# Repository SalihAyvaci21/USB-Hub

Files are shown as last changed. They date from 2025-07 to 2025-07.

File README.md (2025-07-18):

# USB Hub + PD Controller Projesi

Bu proje, USB-C PD (Power Delivery) desteği ile çalışan, 5V-24V arası giriş voltajını kabul eden ve gücü dört farklı çıkışa dağıtan bir **USB Hub** tasarımıdır. Güç ve sinyal yönetimi için çeşitli koruma ve anahtarlama IC’leri entegre edilmiştir.

## 📦 Özellikler

- **Giriş Voltajı (USB-C):** 5V - 24V (PD destekli)
- **Çıkışlar:**
  - 1x **USB-A 3.0**
  - 1x **USB-C 3.0**
  - 1x **FTDI (UART-USB dönüştürücü)**
  - 1x **ST-Link (Programlayıcı / Debugger)**
- **PD Controller:** CH224K (Switch ile kontrol)
- **USB Hub IC:** TUSB8044ARGCR
- **Sinyal Yönlendirme:**
  - 2x HD3SS3202IRSVR (SS MUX, C-to-A ve A-to-C için)
- **Koruma Devreleri:**
  - TPD6S300A (ESD ve güç koruması)
- **Güç Regülasyonu:**
  - 1.1V: TLV71211 (SOT23-5)
  - 3.3V: NCP1117-3.3 (SOT-223)
  - 5V: KA78M05 (TO-252)
- **Programlayıcılar:**
  - ST-Link için STM32F103CBTx
  - FTDI için FT232RL-REEL

## 🛠 Bileşenler

| Bileşen | Açıklama |
|---|---|
| **CH224K** | USB-C PD Controller |
| **TUSB8044ARGCR** | USB 3.0 Hub Controller |
| **HD3SS3202IRSVR** | USB SS MUX (C/A anahtarlama) |
| **TPD6S300A** | USB-C koruma (ESD, VBUS) |
| **TLV71211** | 1.1V LDO Regülatör |
| **NCP1117-3.3** | 3.3V LDO Regülatör |
| **KA78M05** | 5V Regülatör |
| **STM32F103CBTx** | ST-Link Programlayıcı MCU |
| **FT232RL-REEL** | FTDI USB-UART dönüştürücü |

## 📐 Tasarım Özellikleri

- **PD Desteği:** 5V ila 24V arası giriş voltajını otomatik algılar entegre doğru çıkışı verir.
- **Güç Dağıtımı:** TUSB8044ARGCR ile USB 3.0 sinyalleri dört porta bölünür.
- **Sinyal Yönlendirme:** HD3SS3202 ile USB-C ve USB-A arasında yüksek hızlı sinyal yönlendirme.
- **Güvenlik:** TPD6S300A ile USB-C girişinde aşırı gerilim ve ESD koruması.
- **Programlama ve Debug:** Dahili ST-Link (STM32F103CBTx) ve FTDI (FT232RL) arayüzleri.

## 🔌 Kullanım

1. **Giriş Bağlantısı:**
   - USB-C PD girişine adaptör bağlayın (5V-24V arası desteklenir).
2. **Çıkışlar:**
   - USB-A 3.0 portuna cihaz bağlanabilir.
   - USB-C 3.0 portu yüksek hızlı veri aktarımı için kullanılabilir.
   - FTDI portu UART bağlantısı için kullanılabilir.
   - ST-Link portu STM32 debug/programlama için hazırdır.

## ⚡ Koruma ve Güvenlik

- **ESD Koruma:** TPD6S300A
- **Aşırı Gerilim:** PD kontrolcü ile voltaj sınırlaması
- **Sinyal Integrity:** SS MUX ile minimum sinyal kaybı

## 📁 Dosyalar

- `Usb 3. v11.kicad_pro` – KiCAD proje dosyası
- `Usb 3. v11.kicad_sch` – Devre şeması
- `gerber` – Üretim için Gerber dosyaları 
- `BomList.xlsx` – Parça listesi

## ⚠️ Dikkat

> Bu tasarım yüksek hızlı USB sinyalleri ve PD voltajları içerir. Geliştirme ve test sırasında uygun yalıtım ve ESD önlemleri alınmalıdır.

## 📜 Lisans

Bu proje açık kaynaklıdır ve kişisel/akademik kullanım için serbesttir.

---

# USB Hub + PD Controller Project

This project is a **USB Hub** design that operates with USB-C PD (Power Delivery) support, accepting an input voltage range of 5V-24V and distributing power across four different outputs. Various protection and switching ICs are integrated for power and signal management.

## 📦 Features

- **Input Voltage (USB-C):** 5V - 24V (PD supported)
- **Outputs:**
  - 1x **USB-A 3.0**
  - 1x **USB-C 3.0**
  - 1x **FTDI (UART-USB converter)**
  - 1x **ST-Link (Programmer / Debugger)**
- **PD Controller:** CH224K (controlled via switch)
- **USB Hub IC:** TUSB8044ARGCR
- **Signal Routing:**
  - 2x HD3SS3202IRSVR (SS MUX for C-to-A and A-to-C)
- **Protection Circuits:**
  - TPD6S300A (ESD and power protection)
- **Power Regulation:**
  - 1.1V: TLV71211 (SOT23-5)
  - 3.3V: NCP1117-3.3 (SOT-223)
  - 5V: KA78M05 (TO-252)
- **Programmers:**
  - STM32F103CBTx for ST-Link
  - FT232RL-REEL for FTDI

## 🛠 Components

| Component | Description |
|---|---|
| **CH224K** | USB-C PD Controller |
| **TUSB8044ARGCR** | USB 3.0 Hub Controller |
| **HD3SS3202IRSVR** | USB SS MUX (C/A switching) |
| **TPD6S300A** | USB-C protection (ESD, VBUS) |
| **TLV71211** | 1.1V LDO Regulator |
| **NCP1117-3.3** | 3.3V LDO Regulator |
| **KA78M05** | 5V Regulator |
| **STM32F103CBTx** | ST-Link Programmer MCU |
| **FT232RL-REEL** | FTDI USB-UART Converter |

## 📐 Design Features

- **PD Support:** Automatically detects input voltage between 5V and 24V and provides appropriate regulated output.
- **Power Distribution:** USB 3.0 signals are distributed to four ports using TUSB8044ARGCR.
- **Signal Routing:** High-speed signal switching between USB-C and USB-A via HD3SS3202.
- **Protection:** Overvoltage and ESD protection on USB-C input using TPD6S300A.
- **Programming and Debugging:** Integrated ST-Link (STM32F103CBTx) and FTDI (FT232RL) interfaces.

## 🔌 Usage

1. **Input Connection:**
   - Connect an adapter to the USB-C PD input (supports 5V-24V).
2. **Outputs:**
   - USB-A 3.0 port can connect to devices.
   - USB-C 3.0 port supports high-speed data transfer.
   - FTDI port can be used for UART connections.
   - ST-Link port is ready for STM32 debugging/programming.

## ⚡ Protection and Safety

- **ESD Protection:** TPD6S300A
- **Overvoltage:** Voltage limitation via PD controller
- **Signal Integrity:** Minimal signal loss using SS MUX

## 📁 Files

- `Usb 3. v11.kicad_pro` – KiCAD project file
- `Usb 3. v11.kicad_sch` – Schematic file
- `gerber` – Gerber files for production
- `BomList.xlsx` – Bill of Materials

## ⚠️ Warning

> This design involves high-speed USB signals and PD voltages. Proper insulation and ESD precautions must be taken during development and testing.

## 📜 License

This project is open-source and free for personal and academic use.

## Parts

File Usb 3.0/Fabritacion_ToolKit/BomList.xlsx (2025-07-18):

Reference | Value | Digi-Key_PN | MPN | Qty | Supplier | Footprint
C1,C29,C30,C31,C38,C39,C40,C41,C47,C48,C49,C50,C51 | 0.1uF | 399-C0805C104M5RACTUTR-ND | C0805C104M5RACTU | 13 | digikey | Capacitor_SMD:C_0805_2012Metric
C2,C3,C4,C9,C10,C11,C12,C13 | 1uF | 1276-1066-2-ND | CL21B105KAFNNNE | 7 | digikey | Capacitor_SMD:C_0805_2012Metric
C5,C6,C19,C20 | 20pF | 399-C0805C180J5HACTUTR-ND | C0805C180J5HACTU | 2 | digikey | Capacitor_SMD:C_0805_2012Metric
 |  | 399-C0805C180J5HACTUTR-ND | C0805C180J5HACTU | 2 | digikey | Capacitor_SMD:C_0805_2012Metric
C22,C24,C25,C26 | 100nF | 2679-C0805X5R100-104KNE-CT-ND | C0805X5R100-104KNE-CT | 4 | digikey | Capacitor_SMD:C_0805_2012Metric
C35 | 4.7uF | 1276-1244-2-ND | CL21A475KAQNNNE | 1 | digikey | Capacitor_SMD:C_0805_2012Metric
C37 | 0.1uf | 311-1344-2-ND | CC0603KRX7R9BB104 | 1 | digikey | Capacitor_SMD:C_0805_2012Metric
D1,D3,D7,D8 | LTST-C190GKT | 160-1183-1-ND | LTST-C190GKT | 4 | digikey | LED_SMD:LED_0603_1608Metric_Pad1.05x0.95mm_HandSolder
D2 | LTST-C191KRKT | 160-1447-1-ND | LTST-C191KRKT | 1 | digikey | LED_SMD:LED_0603_1608Metric_Pad1.05x0.95mm_HandSolder
D4 | D_Schottky /20V/5A | RB081LAM-20TRTR-ND | RB081LAM-20TR | 1 | digikey | Diode_SMD:D_SOD-128
J1,J3 | KUSBX-SMT-CS2-B30TR | 2092-KUSBX-SMT-CS2-B30TR-ND | KUSBX-SMT-CS2-B30TR | 2 | digikey | KUSBX-SMT3-CS-BTR_KYC
J2 | Conn_01x06 | 2553-2044-1X06G00SB-ND | 2044-1X06G00SB | 1 | digikey | Connector_PinSocket_2.54mm:PinSocket_1x06_P2.54mm_Vertical
J6 | Conn_02x05_Odd_Even | 2553-2044-2X05G00SB-ND | 2044-2X05G00SB | 1 | digikey | Connector_PinSocket_1.27mm:PinSocket_2x05_P1.27mm_Vertical
J7 | USB3_A | GSB316441CEUTR-ND | GSB316441CEU | 1 | digikey | Connector_USB:USB3_A_Molex_48393-001
J8,J10 | USB_A | 2987-CU01SAV0S00-ND | CU01SAV0S00
J9 | Screw_Terminal_01x02 | 5831-1715330000-ND | 1715330000 | 1 | digikey | TerminalBlock:TerminalBlock_MaiXu_MX126-5.0-02P_1x02_P5.00mm
Q1 | BC817-25-TP | BC817-25-TPMSCT-ND | BC817-25-TP | 1 | digikey | Package_TO_SOT_SMD:SOT-23-3
R1 | 100k | 311-100KCRTR-ND | RC0805FR-07100KL | 1 | digikey | Resistor_SMD:R_0805_2012Metric
R2 | 90.9k %1 | 311-90.9KCRTR-ND | RC0805FR-0790K9L | 1 | digikey | Resistor_SMD:R_0805_2012Metric
R3 | 10k %1 | 311-10.0KLRCT-ND | RC0805FR-0710KL | 1 | digikey | Resistor_SMD:R_0805_2012Metric
R4 | 1M | 311-1.0MARTR-ND | RC0805JR-071ML | 1 | digikey | Resistor_SMD:R_0805_2012Metric
R5,R6,R8,R10,R16,R17 | 1k | 311-1.00KCRTR-ND | RC0805FR-071KL | 6 | digikey | Resistor_SMD:R_0805_2012Metric
R7 | 3.5ohm | P3.57KLTR-ND | ERJ-2RKF3571X | 1 | digikey | Resistor_SMD:R_0805_2012Metric
R9 | 0.53k %1 | 2019-RN73R1JTTD5300F100TR-ND | RN73R1JTTD5300F100 | 1 | digikey | Resistor_SMD:R_0805_2012Metric
R11,R12,R13,R14,R18,R19,R36,R40,R20,R21,R24 | 10k | 311-10.0KCRTR-ND | RC0805FR-0710KL | 11 | digikey | Resistor_SMD:R_0805_2012Metric
R20, R21,R24 | 100R | 311-100CRTR-ND | RC0805FR-07100RL | 2 | digikey | Resistor_SMD:R_0805_2012Metric
R25 | 39K | 311-39.0KCRTR-ND | RC0805FR-0739KL | 1 | digikey | Resistor_SMD:R_0805_2012Metric
R26 | 1.5K | RHM1.5KTR-ND | ESR10EZPJ1R5 | 1 | digikey | Resistor_SMD:R_0805_2012Metric
SW1 | SW_DIP_x03 | CT2093MS-ND | 209-3MS | 1 | digikey | Button_Switch_THT:SW_DIP_SPSTx03_Slide_6.7x9.18mm_W7.62mm_P2.54mm_LowProfile
SW2,SW3 | SW_Omron_B3FS | CKN12222-2-ND | PTS526SMG15SMTR2 LFS | 2 | digikey | Button_Switch_SMD:SW_SPST_Omron_B3FS-100xP
TP1,TP2,TP3,TP4,TP5,TP6,TP7,TP8,TP9,TP10,TP11,TP12,TP13 | TestPoint |  |  | 13 | digikey | Connector_Pin:Pin_D1.4mm_L8.5mm_W2.8mm_FlatFork
U1 | CH224K | A0641 | PD/QC/AFC Hızlı Şarj Tetikleme Modülü | 1 | robotronik | Package_SO:SSOP-10-1EP_3.9x4.9mm_P1mm_EP2.1x3.3mm
U2 | TUSB8044ARGCR | 296-53620-2-ND | TUSB8044ARGCR | 1 | digikey | Package_DFN_QFN:VQFN-64-1EP_9x9mm_P0.5mm_EP5.4x5.4mm_ThermalVias
U3 | TPD6S300A | 296-51856-2-ND | TPD6S300ARUKR | 1 | digikey | Package_DFN_QFN:WQFN-20-1EP_3x3mm_P0.4mm_EP1.7x1.7mm_ThermalVias
U4 | NCP1117-3.3_SOT223 | 863-NCP1117LPST33T3G | NCP1117LPST33T3G (https://eu.mouser.com/ProductDetail/onsemi/NCP1117LPST33T3G?qs=kbSN2QblFfKG9A4Foh4YYg%3D%3D) | 1 | digikey | Package_TO_SOT_SMD:SOT-223-3
U5 | STM32F103CBTx | 497-17380-2-ND | STM32F103CBT6TR | 1 | digikey | Package_QFP:LQFP-48_7x7mm_P0.5mm
U6,U8 | HD3SS3202IRSVR | 296-HD3SS3202IRSVRTR-ND | HD3SS3202IRSVR | 2 | digikey | Package_DFN_QFN:UQFN-16-1EP_4x4mm_P0.65mm_EP2.6x2.6mm_ThermalVias
U7 | FT232RL-REEL | 768-1007-1-ND | FT232RL-REEL | 1 | digikey | Package_SO:SSOP-28_5.3x10.2mm_P0.65mm
U9 | KA78M05_TO252 | 511-L7805CDT-TR | L7805CDT-TR | 1 | digikey | Package_TO_SOT_SMD:TO-252-2
U10 | TLV71211_SOT23-5 | 296-30593-2-ND | TLV71211DBVR | 1 | digikey | Package_TO_SOT_SMD:SOT-23-5
XTAL1 | 16Mhz | 535-12830-2-ND | ABLS7M2-16.000MHZ-D2Y-T | 1 | digikey | Crystal:Crystal_SMD_EuroQuartz_EQ161-2Pin_3.2x1.5mm_HandSoldering
Y1 | 24Mhz | ABLS7M2-24.000MHZ-D2Y-T | ABLS7M2-24.000MHZ-D2Y-T | 1 | digikey | Crystal:Crystal_SMD_EuroQuartz_MQ2-2Pin_7.0x5.0mm_HandSoldering

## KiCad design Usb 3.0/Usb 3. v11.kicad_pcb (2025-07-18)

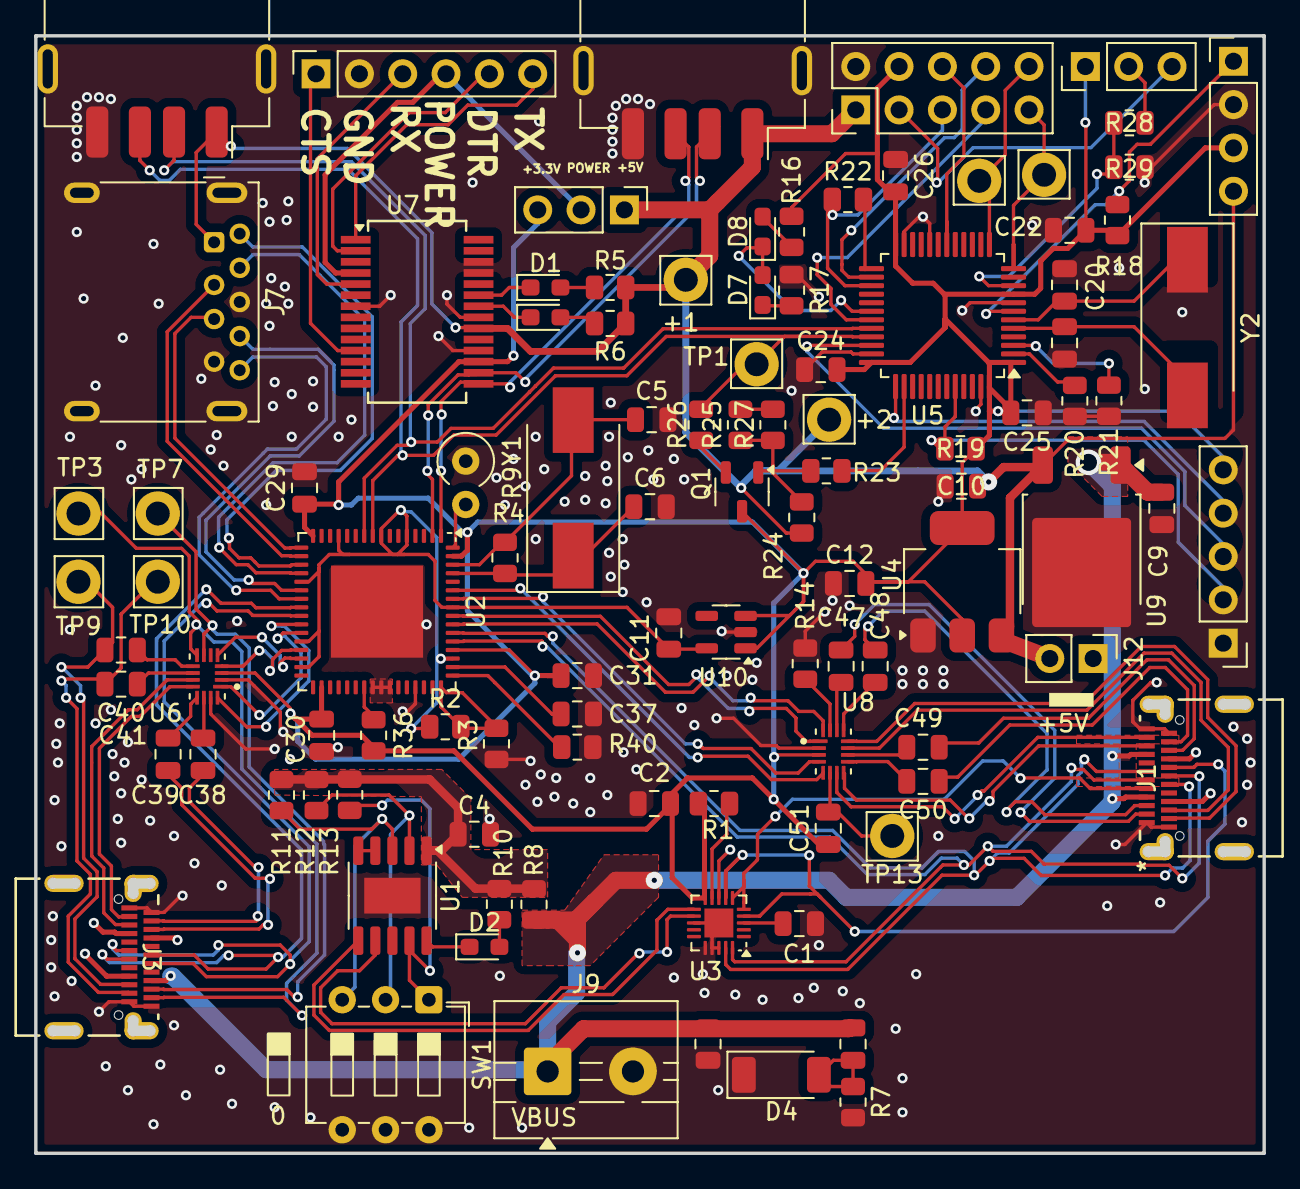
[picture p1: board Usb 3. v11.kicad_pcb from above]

Board: 2 copper layers, 72.0 x 65.5 mm, 103 parts (0 on the bottom side), 108 nets.

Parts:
+1, +2: TestPoint; Pin_D1.4mm_L8.5mm_W2.8mm_FlatFork
C1, C29, C30, C31, C38, C39, C40, C41, C47, C48, C49, C50, C51: 0.1uF; C_0805_2012Metric
C2, C3, C4, C9, C10, C11, C12: 1uF; C_0805_2012Metric
C5, C6, C19, C20: 20pF; C_0805_2012Metric
C22, C24, C25, C26: 100nF; C_0805_2012Metric
C35: 4.7uF; C_0805_2012Metric
C37: 0.1uf; C_0805_2012Metric
D1, D3, D7, D8: LTST-C190GKT; LED_0603_1608Metric_Pad1.05x0.95mm_HandSolder
D2: LTST-C191KRKT; LED_0603_1608Metric_Pad1.05x0.95mm_HandSolder
D4: D_Schottky /20V/5A; D_SOD-128
J1, J3: KUSBX-SMT-CS2-B30TR; KUSBX-SMT3-CS-BTR_KYC
J2: Conn_01x06; PinSocket_1x06_P2.54mm_Vertical
J4: Conn_01x03_Pin; PinHeader_1x03_P2.54mm_Vertical
J5: Conn_01x05_Pin; PinHeader_1x05_P2.54mm_Vertical
J6: Conn_02x05_Odd_Even; PinHeader_2x05_P2.54mm_Vertical
J7: USB3_A; USB3_A_Molex_48393-001
J8, J10: USB_A; USB_A_Receptacle_GCT_USB1046
J9: Screw_Terminal_01x02; TerminalBlock_MaiXu_MX126-5.0-02P_1x02_P5.00mm
J11: Conn_01x04_Pin; PinHeader_1x04_P2.54mm_Vertical
J12: Screw_Terminal_01x02; PinHeader_1x02_P2.54mm_Vertical
JP1: SolderJumper_3_Open; PinHeader_1x03_P2.54mm_Vertical
Q1: BC817-25-TP; SOT-23-3
R1: 100k; R_0805_2012Metric
R2: 90.9k %1; R_0805_2012Metric
R3: 10k %1; R_0805_2012Metric
R4: 1M; R_0805_2012Metric
R5, R6, R8, R10, R16, R17: 1k; R_0805_2012Metric
R7: 3.5ohm; R_0805_2012Metric
R9: 0.53k %1; R_Axial_DIN0309_L9.0mm_D3.2mm_P2.54mm_Vertical
R11, R12, R13, R14, R18, R19, R36, R40: 10k; R_0805_2012Metric
R20, R21, R24: 10K; R_0805_2012Metric
R22, R23: 100R; R_0805_2012Metric
R25: 39K; R_0805_2012Metric
R26: 1.5k; R_0805_2012Metric
R27: 33K; R_0805_2012Metric
R28, R29: 4.7k; R_0805_2012Metric
SW1: SW_DIP_x03; SW_DIP_SPSTx03_Slide_6.7x9.18mm_W7.62mm_P2.54mm_LowProfile
TP1, TP3, TP5, TP6, TP7, TP9, TP10, TP13: TestPoint; Pin_D1.4mm_L8.5mm_W2.8mm_FlatFork
U1: CH224K; SSOP-10-1EP_3.9x4.9mm_P1mm_EP2.1x3.3mm
U2: TUSB8044ARGCR; VQFN-64-1EP_9x9mm_P0.5mm_EP5.4x5.4mm_ThermalVias
U3: TPD6S300A; WQFN-20-1EP_3x3mm_P0.4mm_EP1.7x1.7mm_ThermalVias
U4: NCP1117-3.3_SOT223; SOT-223-3_TabPin2
U5: STM32F103CBTx; LQFP-48_7x7mm_P0.5mm
U6, U8: HD3SS3202IRSVR; QFN40P180X260X55-16N_HD3SS3202RSVT
U7: FT232RL-REEL; SSOP-28_5.3x10.2mm_P0.65mm
U9: KA78M05_TO252; TO-252-2
U10: TLV71211_SOT23-5; SOT-23-5
Y1: 24Mhz; Crystal_SMD_EuroQuartz_MQ2-2Pin_7.0x5.0mm_HandSoldering
Y2: 8Mhz; Crystal_SMD_EuroQuartz_MQ2-2Pin_7.0x5.0mm_HandSoldering

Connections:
1.1v: C11.2, R2.1, U2.5 (VDD), U2.8 (VDD), U2.13 (VDD), U2.21 (VDD), U2.28 (VDD), U2.31 (VDD), U2.51 (VDD), U2.57 (VDD), U10.5 (OUT)
+3.3V: C2.1, C12.2, C22.2, C24.2, C25.2, C26.2, C29.1, C30.1, C31.1, C51.1, J4.1, J5.5, J6.4, J11.3, JP1.3 (B), Q1.3 (C), R1.1, R16.2, R18.1, R19.1, R36.1, U2.16 (VDD33), U2.34 (VDD33), U2.52 (VDD33), U2.63 (VDD33), U3.10 (VPWR), U4.2 (VO), U5.1 (VBAT), U5.9 (VDDA), U5.24 (VDD), U5.36 (VDD), U5.48 (VDD), U6.3 (VCC), U7.17 (3V3OUT), U8.3 (VCC), U10.1 (IN), U10.3 (EN)
+5V: +1.1, +2.1, C10.2, J6.1, J7.1 (VBUS), J8.1 (VBUS), J10.1 (VBUS), J11.4, J12.2, JP1.1 (A), R5.1, R6.1, R24.1, U4.3 (VI), U7.20 (VCC), U9.3 (VO)
/FTDI/POWER: J2.4, JP1.2 (C), U7.4 (VCCIO)
/ST-Link V2/BOOT0: J5.2, R19.2, U5.44 (BOOT0)
/ST-Link V2/CLK: J5.4, U5.37 (PA14)
/ST-Link V2/DIO: J5.3, U5.34 (PA13)
/ST-Link V2/LED: D7.2, D8.1, U5.30 (PA9)
/ST-Link V2/RENUM: R23.2, U5.38 (PA15)
/ST-Link V2/RX: J6.10, TP6.1, U5.13 (PA3)
/ST-Link V2/TX: J6.9, TP5.1, U5.12 (PA2)
/ST-Link V2/T_CLK: J6.8, U5.26 (PB13)
/ST-Link V2/T_DIO: J6.5, R22.1, U5.27 (PB14)
/ST-Link V2/T_NRST: J6.6, U5.18 (PB0)
/ST-Link V2/T_PWR: J4.3, J6.3
/ST-Link V2/T_SWO: J6.7, U5.31 (PA10)
/ST-Link V2/X0: C20.2, U5.6 (PD1), Y2.1
/ST-Link V2/XI: C19.2, U5.5 (PD0), Y2.2
/esdprotection/+: C47.1, J1.A2 (SSTXP1)
/esdprotection/-: C48.1, J1.A3 (SSTXN1)
CFG1: R13.2, SW1.1, U1.9 (CFG1)
CFG2: R12.2, SW1.2, U1.2 (CFG2)
CFG3: R11.2, SW1.3, U1.3 (CFG3)
CTS: J2.1, U7.11 (CTS)
D1N: J8.2 (D-), U2.2 (USB_DM_DN1), U7.16 (USBDM)
D1P: J8.3 (D+), U2.1 (USB_DP_DN1), U7.15 (USBDP)
D2N: J10.2 (D-), U2.10 (USB_DM_DN2), U5.32 (PA11)
D2P: J10.3 (D+), R26.2, TP1.1, U2.9 (USB_DP_DN2), U5.33 (PA12)
D3N: J7.2 (D-), U2.18 (USB_DM_DN3)
D3P: J7.3 (D+), U2.17 (USB_DP_DN3)
D4N: J3.A7 (DN1), J3.B7 (DN2), U2.25 (USB_DM_DN4)
D4P: J3.A6 (DP1), J3.B6 (DP2), U2.24 (USB_DP_DN4)
DN3_RXN: J7.5 (SSRX-), U2.23 (USB_SSRXM_DN3)
DN3_RXP: J7.6 (SSRX+), U2.22 (USB_SSRXP_DN3)
DN3_TXN: J7.8 (SSTX-), U2.20 (USB_SSTXM_DN3)
DN3_TXP: J7.9 (SSTX+), U2.19 (USB_SSTXP_DN3)
DN4_RXN: U2.30 (USB_SSRXM_DN4), U6.5 (A1N)
DN4_RXP: U2.29 (USB_SSRXP_DN4), U6.4 (A1P)
DN4_TXN: U2.27 (USB_SSTXM_DN4), U6.1 (A0N)
DN4_TXP: U2.26 (USB_SSTXP_DN4), U6.16 (A0P)
DTR: J2.5, U7.2 (DTR)
D_N: J1.A7 (DN1), J1.B7 (DN2), U2.54 (USB_DM_UP), U3.19 (D2)
D_P: J1.A6 (DP1), J1.B6 (DP2), U2.53 (USB_DP_UP), U3.20 (D1)
FTDI-RX: J2.3, U7.5 (RXD)
FTDI-TX: J2.6, U7.1 (TXD)
GNDREF: C1.1, C2.2, C3.2, C4.2, C5.2, C6.2, C9.1, C10.1, C11.1, C12.1, C19.1, C20.1, C22.1, C24.1, C25.1, C26.1, C29.2, C30.2, C31.2, C37.2, D4.1 (K), J1.A1 (GND), J1.A12 (GND), J1.B1 (GND), J1.B12 (GND), J2.2, J3.A1 (GND), J3.A12 (GND), J3.B1 (GND), J3.B12 (GND), J5.1, J6.2, J7.4 (GND), J7.7 (DRAIN), J7.10 (SHIELD), J8.4 (GND), J8.5 (Shield), J9.2, J10.4 (GND), J10.5 (Shield), J11.2, R3.1, R7.2, R9.1, R14.2, R17.1, R20.1, R21.1, R29.2, R40.2, SW1.4, SW1.5, SW1.6, U1.11 (GND), U2.40 (BBbmConfigured0_FULLAUTO_FULLPWRMGMT_SS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), U2.41 (PWRCTL_POL), U2.42 (BBEN_GANGED_HS_UP), U2.45 (BBbmConfigured1_AUTOENz_HS_SUSPEND), U2.65 (PAD), U3.8 (GND), U3.13 (GND), U3.16 (GND), U3.17 (GND), U3.18 (GND), U3.21 (GND), U4.1 (GND), U5.8 (VSSA), U5.20 (PB2), U5.23 (VSS), U5.35 (VSS), U5.47 (VSS), U6.2 (GND), U6.15 (OEN), U7.7 (GND), U7.18 (GND), U7.21 (GND), U7.25 (AGND), U7.26 (TEST), U8.2 (GND), U9.2 (GND), U10.2 (GND)
NRST: J11.1, R18.2, U5.7 (NRST)
unnamed: D1.2, R5.2
unnamed: D2.2, R10.1
unnamed: D3.2, R6.2
unnamed: C35.2, D4.2 (A), R7.1
unnamed: D7.1, R17.2
unnamed: D8.2, R16.1
unnamed: J1.A5 (CC1), U3.5 (C_CC2), U3.6 (RPD_G2)
unnamed: J1.B5 (CC2), U3.4 (C_CC1), U3.7 (RPD_G1)
unnamed: C49.1, J1.B3 (SSTXN2)
unnamed: C50.1, J1.B2 (SSTXP2)
unnamed: J4.2, R28.1
unnamed: Q1.1 (B), R23.1, R24.2, R25.1, R27.1
unnamed: Q1.2 (E), R26.1
unnamed: R25.2, R27.2
unnamed: U1.4 (DP), U1.5 (DM)
unnamed: D2.1, U1.10 (PG)
unnamed: C37.1, U2.50 (GRST_N)
unnamed: R36.2, U2.39 (SMBUS_SS_SUSPEND_N)
unnamed: R40.1, U2.49 (TEST)
unnamed: R9.2, U2.64 (USB_R1)
unnamed: R2.2, R3.2, U2.48 (USB_VBUS)
unnamed: C5.1, R4.1, U2.62 (XI), Y1.2
unnamed: C6.1, R4.2, U2.61 (XO), Y1.1
unnamed: C1.2, U3.3 (VBIAS)
unnamed: R1.2, U3.9 (~FLT)
unnamed: R28.2, R29.1, U5.10 (PA0)
unnamed: R22.2, U5.25 (PB12)
unnamed: R20.2, U5.2 (PC13)
unnamed: R21.2, U5.3 (PC14)
unnamed: C39.1, U6.13 (B0N)
unnamed: C38.1, U6.14 (B0P)
unnamed: C41.1, U6.9 (C0N)
unnamed: C40.1, U6.10 (C0P)
unnamed: D1.1, U7.23 (CBUS0)
unnamed: D3.1, U7.22 (CBUS1)
unnamed: R14.1, U8.15 (OEN)
unnamed: C51.2, TP13.1, U8.6 (SEL)
PD_CC1: U1.7 (CC1), U3.12 (CC1)
PD_CC2: U1.6 (CC2), U3.11 (CC2)
RX1+: U2.58 (USB_SSRXP_UP), U8.4 (A1P)
RX1-: U2.59 (USB_SSRXM_UP), U8.5 (A1N)
RX1A+: J1.B11 (SSRXP1), U8.12 (B1P)
RX1A-: J1.B10 (SSRXN1), U8.11 (B1N)
RX1N: J3.B10 (SSRXN1), U6.11 (B1N)
RX1P: J3.B11 (SSRXP1), U6.12 (B1P)
RX2A+: J1.A11 (SSRXP2), U8.7 (C1N)
RX2A-: J1.A10 (SSRXN2), U8.8 (C1P)
RX2N: J3.A10 (SSRXN2), TP7.1, U6.7 (C1N)
RX2P: J3.A11 (SSRXP2), TP3.1, U6.8 (C1P)
TX1+: U2.55 (USB_SSTXP_UP), U8.16 (A0P)
TX1-: U2.56 (USB_SSTXM_UP), U8.1 (A0N)
TX1A_N: C48.2, U8.13 (B0N)
TX1A_P: C47.2, U8.14 (B0P)
TX1N: C39.2, J3.A3 (SSTXN1)
TX1P: C38.2, J3.A2 (SSTXP1)
TX2A+: C50.2, U8.9 (C0N)
TX2A-: C49.2, U8.10 (C0P)
TX2N: C41.2, J3.B3 (SSTXN2), TP9.1
TX2P: C40.2, J3.B2 (SSTXP2), TP10.1
VBUS: C3.1, C9.2, C35.1, J1.A4 (VBUS), J1.A9 (VBUS), J1.B4 (VBUS), J1.B9 (VBUS), J3.A4 (VBUS), J3.A9 (VBUS), J3.B4 (VBUS), J3.B9 (VBUS), J9.1, J12.1, R8.1, U9.1 (VI)
VDD: C4.1, R8.2, R10.2, R11.1, R12.1, R13.1, U1.1 (VDD)
